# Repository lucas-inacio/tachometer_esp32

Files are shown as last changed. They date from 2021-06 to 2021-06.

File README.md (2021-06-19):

# tachometer_esp32
A tachometer targeting orbital shakers

## Principle of operation
Orbital shakers perform a horizontal, circling movement of its table to mix the samples of interest.
By sampling the acceleration of the table one can extract the main frequency component using the Fourier Transform.
With this information it's easy to get the speed of rotation by simply multiplying the frequency in hertz by a factor of 60, thus resulting in rotations per minute (RPM).

The circuit must be firmly attached to the table in the horizontal position (with z axis perpendicular) so the accelerometer can be read properly.
Currently only the x axis is taken into account for the computation (the y component should provide the same information for a perfect orbital movement).

To report the data the ESP32 uses the BluetoothSerial interface. Any bluetooth enabled computer or smartphone can read the data by pairing with
the device named "Agitador Orbital" (Orbital Shaker). A string with only numbers will be sent each second.

## Tools
* Software
  * [kissfft](https://github.com/mborgerding/kissfft) - Using its FFT implementation
  * [Arduino core for the ESP32](https://github.com/espressif/arduino-esp32)
  * [Fritzing](https://fritzing.org/) - For the diagram below
* Hardware
  * ESP32 Devkit V1
  * ADXL345 Accelerometer

## Known issues
I haven't been able to get bluetooth working with version 1.0.6 of the arduino-esp32 core. Opening the virtual COM port in the computer shows up an error at the ESP32 side.
The solution for now is to downgrade to 1.0.4.

## Test circuit
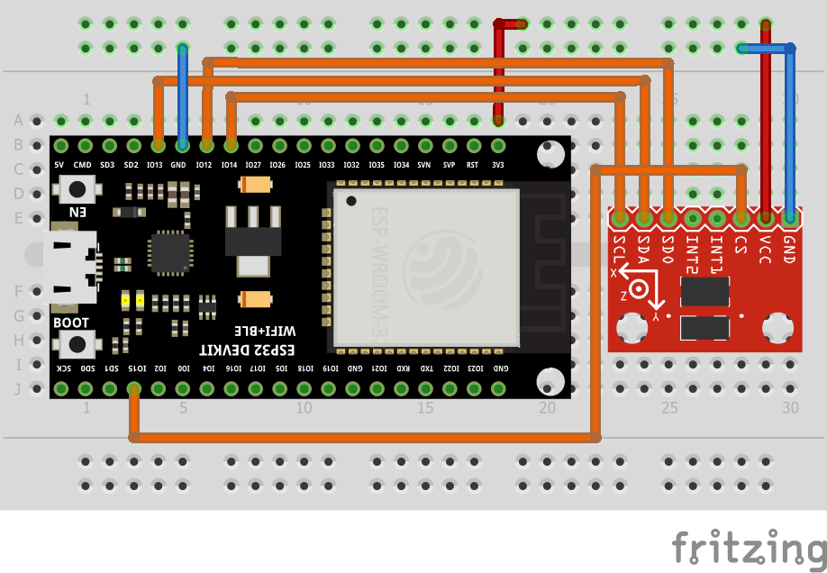
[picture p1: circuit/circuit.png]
Example circuit


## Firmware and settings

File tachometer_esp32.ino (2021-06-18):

#include <iomanip>
#include <sstream>
#include <vector>

#include <BluetoothSerial.h>
#include <SPI.h>
#include "kiss_fftr.h"

#if !defined(CONFIG_BT_ENABLED) || !defined(CONFIG_BLUEDROID_ENABLED)
#error Bluetooth is not enabled! Please run `make menuconfig` to and enable it
#endif

#define HSPI_SS      15
#define SPI_CLK      1000000

// Endereços dos registradores do acelerômetro ADXL345
#define DEVICE_ID    0x00
#define BW_RATE      0x2C // Rate bits configurados como 1010 (100Hz) por padrão
#define POWER_CTL    0x2D
#define DATA_FORMAT  0x31
#define DATAX0       0x32
#define DATAX1       0x33
#define DATAY0       0x34
#define DATAY1       0x35
#define DATAZ0       0x36
#define DATAZ1       0x37
#define FIFO_CTL     0x38

#define SAMPLE_RATE      32
#define SAMPLE_PERIOD_US 31250
#define SIGNAL_LENGTH    256
#define THRESHOLD        0.2f
#define ACCEL_RATIO      (4.0f / 1024)

void setup_accel(uint cs_pin, SPIClass *adxl345) {
    pinMode(cs_pin, OUTPUT);
    digitalWrite(cs_pin, HIGH);

    uint8_t values[] = { FIFO_CTL, 0x8F };
    adxl345->beginTransaction(SPISettings(SPI_CLK, MSBFIRST, SPI_MODE3));
    digitalWrite(cs_pin, LOW);
    adxl345->transfer(values, 2);
    digitalWrite(cs_pin, HIGH);
    adxl345->endTransaction();

    // O ADXL345 inicia em modo de espera. 0x08 (00001000) inicia amostragem
    values[0] = POWER_CTL;
    values[1] = 0x08;
    adxl345->beginTransaction(SPISettings(SPI_CLK, MSBFIRST, SPI_MODE3));
    digitalWrite(cs_pin, LOW);
    adxl345->transfer(values, 2);
    digitalWrite(cs_pin, HIGH);
    adxl345->endTransaction();
}

void read_accelerometer(uint cs_pin, SPIClass *adxl345, int16_t *x, int16_t *y, int16_t *z) {
    uint8_t buffer[6] = { 0 };
    uint8_t reg = DATAX0;
    reg |= 0xC0; // Modo de leitura, múltiplos bytes

    adxl345->beginTransaction(SPISettings(SPI_CLK, MSBFIRST, SPI_MODE3));
    digitalWrite(cs_pin, LOW);
    adxl345->transfer(&reg, 1);
    adxl345->transferBytes(nullptr, buffer, 6);
    digitalWrite(cs_pin, HIGH);
    adxl345->endTransaction();

    *x = buffer[0] | (buffer[1] << 8);   
    *y = buffer[2] | (buffer[3] << 8);   
    *z = buffer[4] | (buffer[5] << 8);
}

BluetoothSerial SerialBT;

std::vector<float> samples;
kiss_fftr_cfg fftcfg;
kiss_fft_cpx freqData[SIGNAL_LENGTH];
float currentRPM;

SPIClass adxl345;
unsigned long sampleTimestamp, printTimestamp;
void setup() {
    SerialBT.begin("Agitador Orbital");

    // Configura a acelerômetro
    adxl345.begin();
    setup_accel(HSPI_SS, &adxl345);

    // Inicializa o buffer de saída para cálculo da FFT
    fftcfg = kiss_fftr_alloc(SIGNAL_LENGTH, false, 0, 0);

    sampleTimestamp = micros();
    printTimestamp = sampleTimestamp;
}

void loop() {
    unsigned long now = micros();
    if (now - sampleTimestamp >= SAMPLE_PERIOD_US) {
        sampleTimestamp = now;

        int16_t x, y, z;
        read_accelerometer(HSPI_SS, &adxl345, &x, &y, &z);
        samples.push_back(x * ACCEL_RATIO);
        if (samples.size() > SIGNAL_LENGTH) // Remove amostra mais antiga
            samples.erase(samples.begin());
        
        // Calcula a FFT
        kiss_fftr(fftcfg, samples.data(), freqData);

        // Encontra a maior componente de frequência
        int biggestIndex = 0;
        float maxValue = freqData[0].r * freqData[0].r + freqData[0].i * freqData[0].i;
        int i;
        for (i = 1; i < SIGNAL_LENGTH / 2; ++i) {
            float mag = freqData[i].r * freqData[i].r + freqData[i].i * freqData[i].i;
            // Descarta ruídos
            if (mag >= THRESHOLD && mag > maxValue) {
                maxValue = mag;
                biggestIndex = i;
            }
        }
        // Converte para RPM
        currentRPM = biggestIndex * 60.0f * SAMPLE_RATE / SIGNAL_LENGTH;
    }

    if (now - printTimestamp > 1000000) {
        printTimestamp = now;

        std::stringstream message;
        message << std::setprecision(2) << std::showpoint << std::fixed << currentRPM << std::endl;
        SerialBT.write(
          reinterpret_cast<const uint8_t*>(message.str().c_str()), message.str().size());
    }
}

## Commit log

2021-06-19 Added schematics
    [circuit.fzz]
2021-06-19 Updated circuit.fzz file
    [circuit.fzz]
